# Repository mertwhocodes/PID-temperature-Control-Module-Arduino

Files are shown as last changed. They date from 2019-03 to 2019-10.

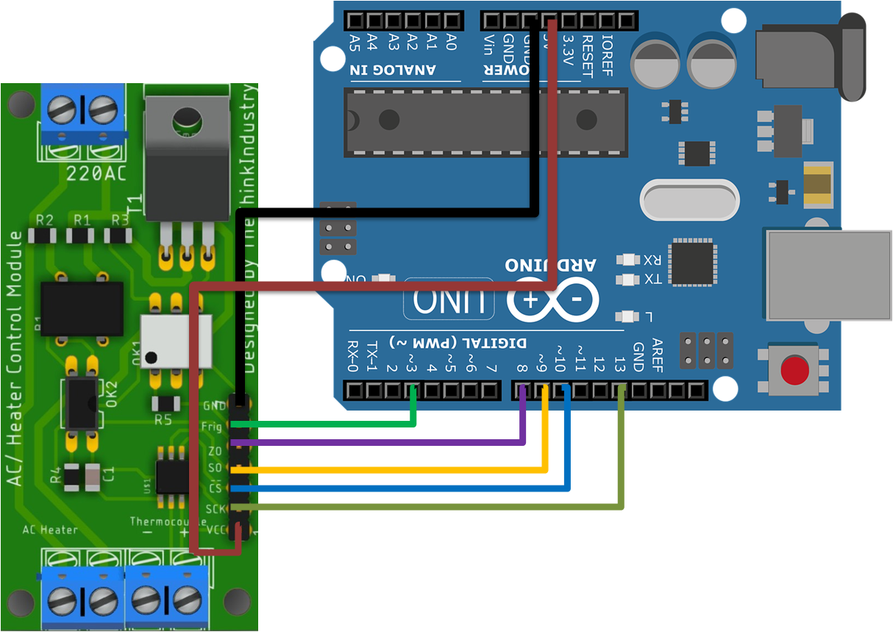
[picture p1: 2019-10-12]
Documentation/arduino connection.png

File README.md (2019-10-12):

 # Heater-PID-Control-Module-
PID_CONTROL_MODULE2
**Close loop PID Heater Control Module**

This module designed to control AC Clamp heater or any AC heater with PID algorithm.
That module use Max6675 Cold-Junction-Compensated K-Thermocoupleto-Digital Converter to mesure 
temperature of heater.First you have to include max6675.h on arduino ide.
# **Companent list**
- Max6675
- BTA-16 triac
- Moc3020
- Pc817
- D1208 rectifier
- K-type thermocouple
- 2x47k res
- 100 res
- 200 res
- 1k res
- 0.1µF con
# Installation 
> go get [github.com/merttuncell/Heater-PID-Control-Module-](https://github.com/merttuncell/Heater-PID-Control-Module- )

> add Max6675.h  arduino library from [ https://github.com/adafruit/MAX6675-library]( https://github.com/adafruit/MAX6675-library)
# Arduino Connection
arduino connection

# Pin Configuration

- **GND** - Ground
- **Frig** - Triger pin for Triac  
- **Z0** - AC Voltage ZeroOut dedection output pin high when [zero cross](https://en.wikipedia.org/wiki/Zero_crossing_control )  dedection
- **SO** - Serial Data Output For MAX6675
- **CS** - Ship Select Set CS low to enable the serial interface 
- **SCK** - Serial Clock Input 
- **VCC** - Positive Supply (3V-5.5V)

# Repository Contents

- **/Documentation** - Datasheets, additional product information

- **/Frimware** - Example code for Arduino

- **/Hardware** - Eagle design files(.brd, .sch)

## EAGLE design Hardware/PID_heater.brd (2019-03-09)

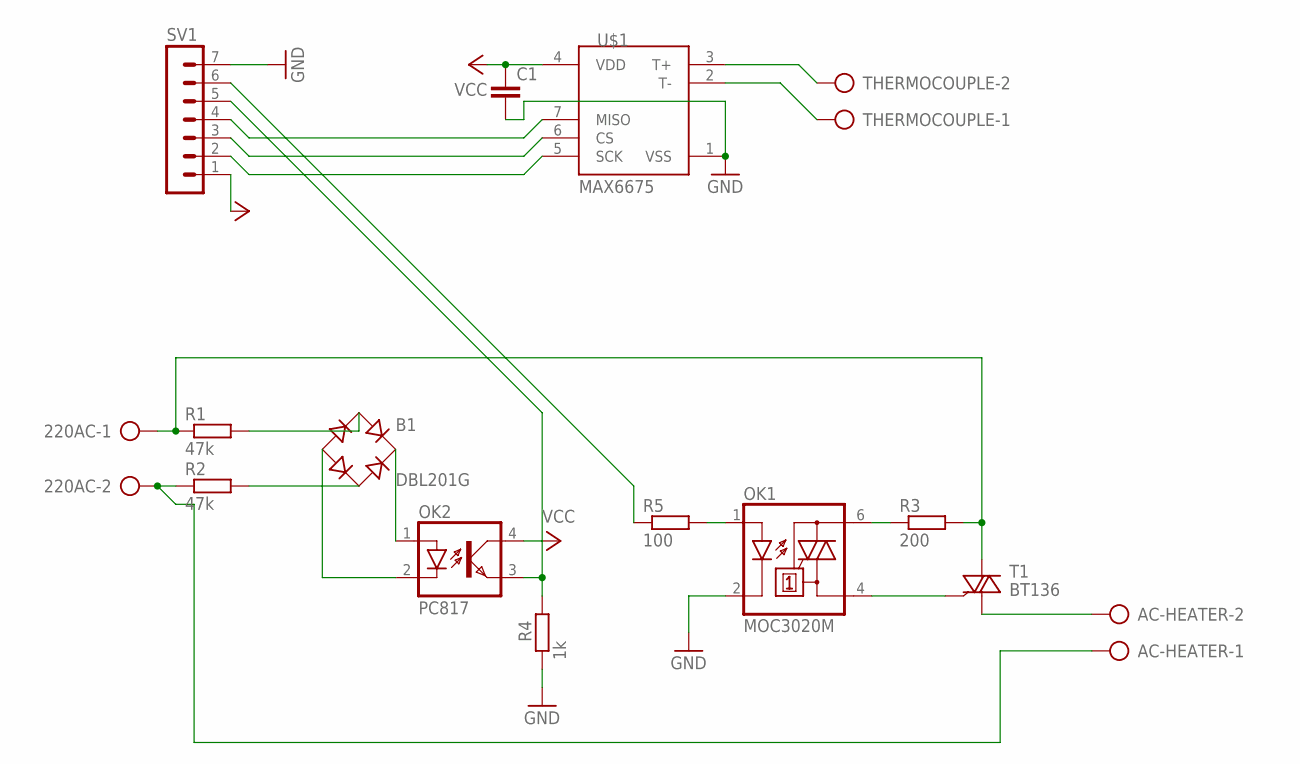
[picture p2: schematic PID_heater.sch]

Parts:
220AC: AK300/2
AC-HEATER: AK300/2
B1: DBL201G; DB
C1: 0.1u; C0805
OK1: MOC3020M; DIL06
OK2: PC817; DIL04
R1, R2: 47k; R0805
R3: 200; R0805
R4: 1k; R0805
R5: 100; R0805
SV1: MA07-1
T1: BT136; TO220AB
THERMOCOUPLE: AK300/2
U$1: MAX6675; SO08

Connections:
GND: C1.2, OK1.2 (C), R4.1, SV1.7, U$1.1 (VSS)
unnamed: OK1.6 (A2), R3.1
unnamed: 220AC.1, R1.1, R3.2, T1.2 (A2)
unnamed: 220AC.2, AC-HEATER.1, R2.1
unnamed: B1.AC1, R1.2
unnamed: B1.AC2, R2.2
unnamed: B1.+, OK2.1 (A)
unnamed: B1.-, OK2.2 (C)
unnamed: OK2.3 (EMIT), R4.2, SV1.5
unnamed: OK1.1 (A), R5.2
unnamed: OK1.4 (A1), T1.3 (G)
unnamed: THERMOCOUPLE.2, U$1.3 (T+)
unnamed: AC-HEATER.2, T1.1 (A1)
unnamed: THERMOCOUPLE.1, U$1.2 (T-)
unnamed: R5.1, SV1.6
unnamed: SV1.4, U$1.7 (MISO)
unnamed: SV1.3, U$1.6 (CS)
unnamed: SV1.2, U$1.5 (SCK)
VCC: C1.1, OK2.4 (COL), SV1.1, U$1.4 (VDD)

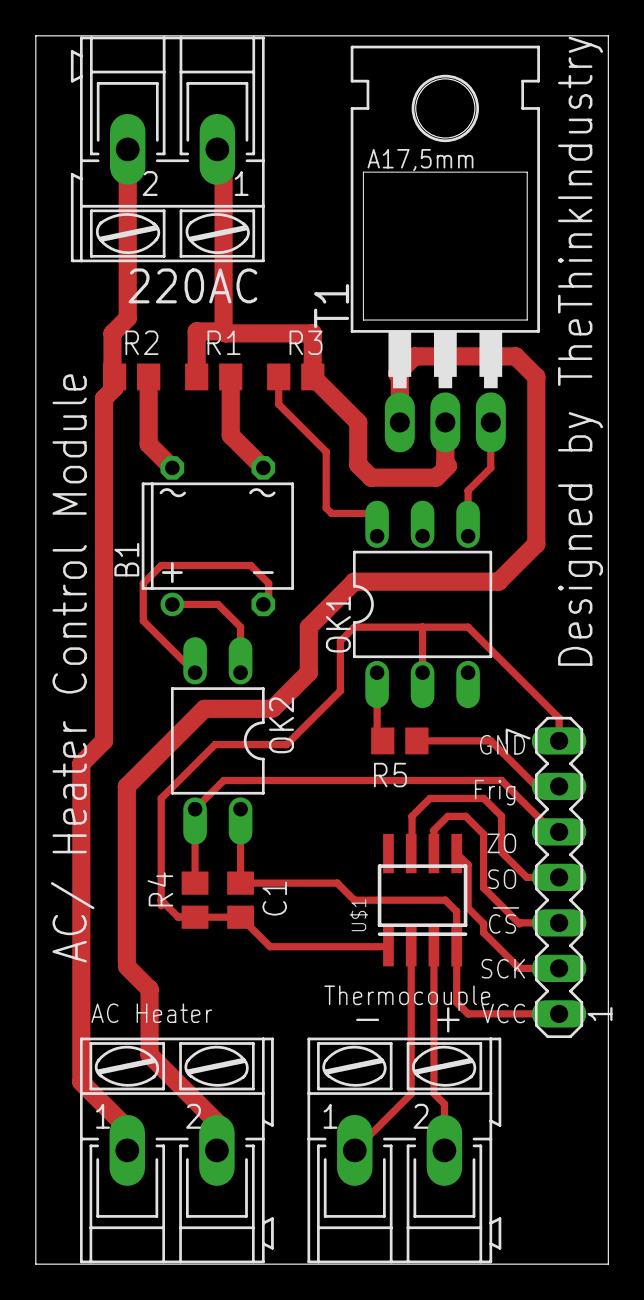
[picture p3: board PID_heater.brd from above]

Board: 2 copper layers, 32.0 x 68.6 mm, 15 parts (0 on the bottom side), 19 nets.

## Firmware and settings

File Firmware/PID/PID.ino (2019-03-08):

// Visual Micro is in vMicro>General>Tutorial Mode
//


#include"max6675.h"

#define HEATER_TRIGGER 3
#define SET_POINT_1 210
#define MAX_TRIGGER_DELAY 7400 
#define TEMP_READ_DELAY 500
#define thermoDO 9
#define thermoCS 10
#define thermoCLK 13
#define ZERO_CROSS 8
int last_CH1_state = 0;
bool zero_cross_detected = false;
  typedef struct {
  double PState;
  double iState;
  double DState;
  double iGain,
    dGain,
    pGain;

}PID;
PID pid_1;
double PID_error_1, PID_previous_error_1 = 0;
unsigned long current_millis = 0;
unsigned long previousMillis, previousMillis1 = 0;
double PID_value = 0;
float real_temperature = 0;
float elapsedTime, Time, timePrev;
bool func_trigger = false;

MAX6675 thermocouple_1(thermoCLK, thermoCS, thermoDO);
void setup()
{
  Serial.begin(9600);
  //timer_2_init();
  pinMode(HEATER_TRIGGER, OUTPUT);
  pinMode (ZERO_CROSS,INPUT); 
  digitalWrite(HEATER_TRIGGER, LOW);
  PCICR |= (1 << PCIE0);    //enable PCMSK0 scan                                                 
  PCMSK0 |= (1 << PCINT0);  //Set pin D8 (zero cross input) trigger an interrupt on state change.
  pid_1.pGain = 125;
  pid_1.iGain = 2.5;
  pid_1.dGain =3;
}

void loop()
{
  current_millis = millis();

  if (current_millis - previousMillis >= TEMP_READ_DELAY)
  {
    previousMillis += TEMP_READ_DELAY;
    real_temperature = thermocouple_1.readCelsius();
    PID_error_1 = SET_POINT_1 - real_temperature;
    if (PID_error_1 > 30)
    {
      pid_1.iState = 0;
    }
    pid_1.PState = pid_1.pGain * PID_error_1;
    pid_1.iState += (pid_1.iGain*PID_error_1);
    timePrev = Time;
    Time = millis();
    elapsedTime = (Time - timePrev) / 1000;
    pid_1.DState = pid_1.dGain*((PID_error_1 - PID_previous_error_1) / elapsedTime);
    PID_value = pid_1.PState + pid_1.iState + pid_1.DState;
    if (PID_value < 0)
    {
      PID_value = 0;
    }
    if (PID_value > MAX_TRIGGER_DELAY)
    {
      PID_value = MAX_TRIGGER_DELAY;
    }
  /* Serial.print("Set: ");
    Serial.print(SET_POINT_1);
    Serial.print("    Real temp: ");
    Serial.print(real_temperature);
    Serial.print("   PID: ");
    Serial.print(PID_value);
    Serial.print("   p: ");
    Serial.print(pid_1.PState);
    Serial.print("   I: ");
    Serial.print(pid_1.iState);
    Serial.print("   D: ");
    Serial.println(pid_1.DState);*/
    Serial.println(real_temperature);
   //Serial.print("   PID: ");
   //Serial.println(PID_value);
    PID_previous_error_1 = PID_error_1;
  }
  if (zero_cross_detected)     
    {
    delayMicroseconds(MAX_TRIGGER_DELAY-PID_value);
     digitalWrite(HEATER_TRIGGER, HIGH);
    delayMicroseconds(100);
     digitalWrite(HEATER_TRIGGER, LOW);
     zero_cross_detected = false;
  }

}
ISR(PCINT0_vect){
  if(PINB & B00000001){          
    if(last_CH1_state == 0){     
      zero_cross_detected = true;
    }
  }
  else if(last_CH1_state == 1){        
    zero_cross_detected = true;  
    last_CH1_state = 0;              }
  }

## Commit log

2019-03-08 Designed
    PID Header Control Module
    [PID_heater.brd, PID_heater.sch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]
2019-03-08 Create PID.ino
    PID Kodları eklendi
2019-03-09 Wires width changed
    pin Names and TheThinkIndustry Logos Added
    [PID_heater.brd]
2019-03-09 R1-R2-R3 wires width changed
    [PID_heater.brd]
2019-03-09 logo location changed
    [PID_heater.brd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]
2019-10-12 Create arduino connection.png
